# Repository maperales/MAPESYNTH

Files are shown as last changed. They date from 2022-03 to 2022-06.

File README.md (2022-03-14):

# MAPESYNTH
Documentación y ficheros de diseño y programación del sistema Mapesynth
-
En este repositorio se encuentra toda la información necesaria para poder replicar el sistema MAPESYNTH completo.

El sistema MAPESYNTH (Midi Advanced Programmable Educational Synthesizer) es un dispositivo que, convenientemente programado, puede hacer de instrumento MIDI, controlador MIDI, secuenciador MIDI y sintetizador MIDI, o cualquier combinación de las anteriores. Al ser de código abierto, puede ser reprogramado para cumplir otras funciones.



El hardware tiene la estructura de un Boosterpack tipo XL (40 pines), que se puede acomodar sobre multitud de Launchpads de Texas Instruments. En concreto, los ejemplos software y el diseño están enfocados al uso del microcontrolador MSP430FR5994, por lo que será necesario disponer del Launchpad MSP-EXP430FR5994 para su manejo. Los ficheros de diseño se encuentran en Eagle, aunque la etapa final se ha realizado en EasyEDA. Se ofrece igualmente el fichero de EasyEDA, por si sólo se desea fabricar tal cual, sin ningún cambio.

El software se ha desarrollado en Code Composer Studio, disponible de manera gratuita en la página de Texas Instruments. Probablemente se pueda reutilizar con algunos cambios menores con otros compiladores de la familia MSP430, aunque no se ha probado.

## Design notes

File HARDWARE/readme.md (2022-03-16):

Ficheros de Hardware
==
En esta carpeta están los ficheros necesarios para replicar el hardware del sistema MAPESYNTH. En la carpeta EAGLE se encuentran los ficheros de Eagle, por si se quiere hacer alguna variación de los mismos. Están diseñados con la versión Eagle Standard (free) 7.7.0, accesible aún (espero) en la página web de Autodesk:

http://eagle.autodesk.com/eagle/software-versions/1

Se incluye el fichero de esquema, el rutado, y un fichero de librería con los elementos usados. 


Aparte de los ficheros fuente, se ofrecen también, en la carpeta EasyEDA, el fichero (comprimido) con el GERBER de la placa para ser fabricada, y el archivo de EasyEDA que se ha creado para ello. Este archivo también es editable, pero no tiene "soporte de esquema", está importado directamente como PCB desde Eagle y modificado para añadirle la última capa de serigrafía y el acabado final. 


Respecto a la lista de componentes, se indican los enlaces de los diferentes elementos que se han comprado para el desarrollo de la placa. Muchos de ellos son críticos en cuanto a la forma y tamaño de la huella (potenciómetros, joystick, pantalla...) y otros son estándar (resistencias y condensadores SMD o thru hole)

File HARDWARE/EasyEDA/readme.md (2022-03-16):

Ficheros EasyEDA
--
En esta carpeta se encuentra el fichero para poder modificar la versión final del diseño (mapesynth.json), en EasyEDA. Este software se puede ejecutar en modo online en su propia página web
o bien descargarlo para ejecutarlo como aplicación de escritorio. La principal ventaja es asegurar la compatibilidad con la empresa JLCPCB, fabricante de prototipos de PCB
con coste bastante contenido. 

Igualmente, si no se quiere hacer ningún cambio en absoluto, se puede usar el fichero comprimido que tiene los archivos GERBER necesarios para la fabricación (mapesynth.zip), y tal cual se puede 
mandar a fabricar.

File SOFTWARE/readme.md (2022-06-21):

Software de manejo del sistema MAPESYNTH
--

En esta carpeta se incluye todo el sw necesario para hacer funcionar el sistema, así como varios ejemplos de manejo del mismo. Cada ejemplo se incluye en un fichero .c 

Los siguentes ficheros son necesarios para el funcionamiento de los ejemplos:

- **mapesynth.c / mapesynth.h**: librería de funciones de manejo del sistema. Incluye las funciones de bajo nivel (HAL) y las funciones de manejo en alto nivel, así como algunas funciones de manejo de la pantalla.
- **formas.h / formas.c**: formas de onda digitalizadas, y definiciones de constantes para calcular las fases al muestrear las formas con las frecuencias de las notas de la escala occidental temperada (LA=440Hz). Solo será necesario si se va a usar el sistema como sintetizador
- **nokia5110.c / nokia5110.h**: librería de funciones de manejo de la pantalla. Basada en la existente en la página 43oh.com

Los ejemplos disponibles son los siguientes:

- **MIDI_CTRL1.c**: El sistema funciona como un secuenciador, reproduciendo canciones almacenadas. Se puede elegir la canción, cambiar la velocidad y seleccionar el canal MIDI al que se mande la secuencia.
- **MIDI_CTRL2.c**:El sistema funciona como un controlador MIDI interpuesto entre un teclado y un sintetizador. Cuando recibe una nota, la retransmite, pudiendo modificar la nota, el valor de la velocidad y el pitch. También podrá incluir mensajes de Pedal Sustain On/Off.
- **MIDI_SYNTH1.c**: Funciona como sintetizador aditivo básico, sumando cualquiera de las formas almacenadas, pudiendo variar en el momento de la suma su amplitud y fase
- **MIDI_SYNTH2.C**: versión del anterior, incorporando la modulación ADSR. Se pueden variar los parámetros de tiempos de ataque, decay, release y valor de Sustain.  
- **MIDI_SYNTH3.C**: Versión del anterior, incorporando la posibilidad de grabar formas de onda ya mezcladas y recuperarlas más adelante. Hace uso de la memoria FRAM del dispositivo, y cambia ligeramente el uso de los vectores de forma de onda.

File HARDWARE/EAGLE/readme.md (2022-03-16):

Ficheros EAGLE
--
En principio, bastará con copiar los ficheros .brd y .sch en el mismo directorio para poder abrirlos. El fichero de librería (.lbr) se ofrece como compilación de los elementos, pero probablemente no sea necesario.

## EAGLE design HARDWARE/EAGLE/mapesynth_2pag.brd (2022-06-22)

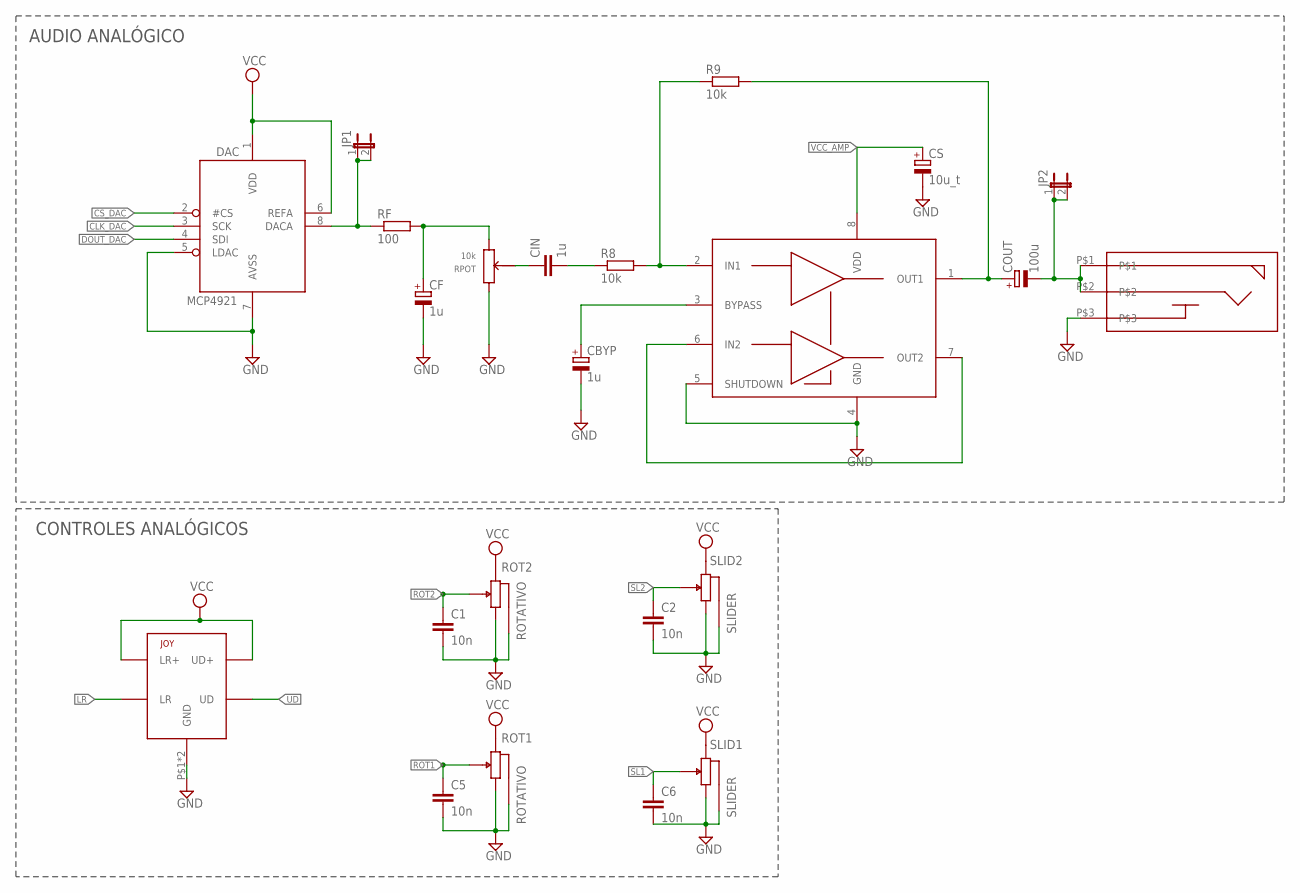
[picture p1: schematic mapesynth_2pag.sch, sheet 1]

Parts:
AMP: TPA6111; SO-08
C1, C2, C5, C6: 10n; C050-024X044
CBYP: 1u; 153CLV-0405
CF: 1u; 153CLV-0405
CIN: 1u; C1206
COUT: 100u; 153CLV-0605
CS: 10u_t; CT3528
DAC: MCP4921EN_SMD; SO-08
JOY: JOYSTICK; PLACAJSTICK
JP1, JP2: JP1E; JP1
R8, R9: 10k; M1206
RF: 100; M1206
ROT1, ROT2: ROTATIVO
RPOT: 10k; POT_VOL
SLID1, SLID2: SLIDER
U$4: JACK_3_5MM_VA; JACK3_5MM_V2

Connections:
CLK_DAC: DAC.3 (SCK); also elsewhere on the board
CS_DAC: DAC.2 (#CS); also elsewhere on the board
DOUT_DAC: DAC.4 (SDI); also elsewhere on the board
GND: AMP.4 (GND), AMP.5 (SHUTDOWN), C1.2, C2.2, C5.2, C6.2, CBYP.-, CF.-, CS.-, DAC.5 (LDAC), DAC.7 (AVSS), JOY.P$1 (GND), JOY.P$8 (GND), ROT1.A (1), ROT1.GND1 (GND), ROT1.GND2 (GND), ROT2.A (1), ROT2.GND1 (GND), ROT2.GND2 (GND), RPOT.P$1, SLID1.1, SLID1.4 (GND), SLID1.5 (GND), SLID1.6 (GND), SLID1.7 (GND), SLID2.1, SLID2.4 (GND), SLID2.5 (GND), SLID2.6 (GND), SLID2.7 (GND), U$4.P$3; also elsewhere on the board
LR: JOY.P$3 (LR), JOY.P$6 (LR); also elsewhere on the board
unnamed: DAC.8 (DACA), JP1.1, JP1.2, RF.1
unnamed: CF.+, RF.2, RPOT.P$3
unnamed: CIN.1, RPOT.P$2
unnamed: CIN.2, R8.1
unnamed: AMP.2 (IN1), R8.2, R9.1
unnamed: AMP.1 (OUT1), COUT.+, R9.2
unnamed: COUT.-, JP2.1, JP2.2, U$4.P$1, U$4.P$2
unnamed: AMP.6 (IN2), AMP.7 (OUT2)
unnamed: AMP.3 (BYPASS), CBYP.+
ROT1: C5.1, ROT1.C (2); also elsewhere on the board
ROT2: C1.1, ROT2.C (2); also elsewhere on the board
SL1: C6.1, SLID1.2; also elsewhere on the board
SL2: C2.1, SLID2.2; also elsewhere on the board
UD: JOY.P$2 (UD), JOY.P$7 (UD); also elsewhere on the board
VCC: DAC.1 (VDD), DAC.6 (REFA), JOY.P$4 (LR+), JOY.P$5 (UD+), ROT1.B (3), ROT2.B (3), SLID1.3, SLID2.3; also elsewhere on the board
VCC_AMP: AMP.8 (VDD), CS.+; also elsewhere on the board

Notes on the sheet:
AUDIO ANALÓGICO
CONTROLES ANALÓGICOS

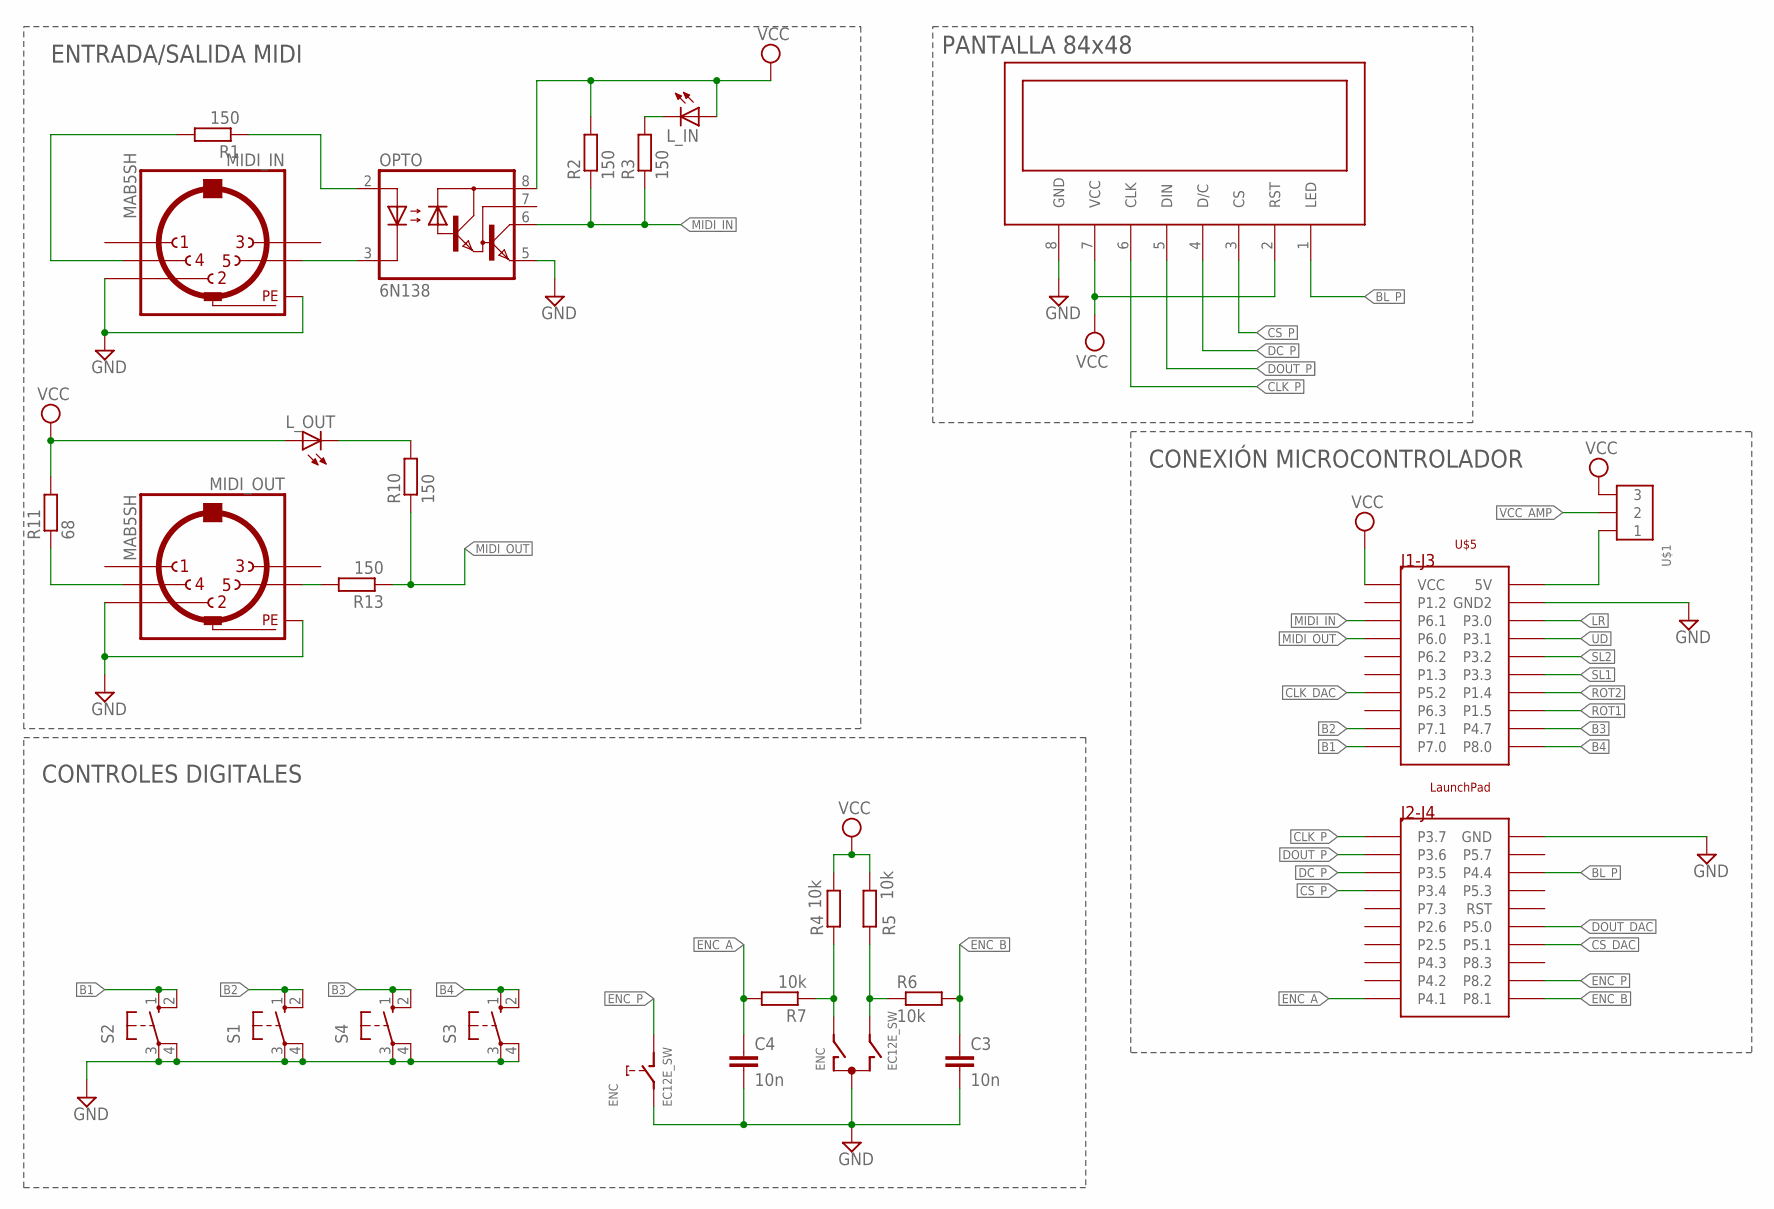
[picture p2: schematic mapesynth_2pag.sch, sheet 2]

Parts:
C3, C4: 10n; C050-024X044
ENC: EC12E_SW; ALPS_EC12E_SW
L_IN: LED5MM
L_OUT: LED5MM
MIDI_IN: MAB5SH
MIDI_OUT: MAB5SH
OPTO: 6N138; DIL08
R1, R2, R3, R10, R13: 150; 0207/10
R4, R5, R6, R7: 10k; R1206
R11: 68; 0207/10
S1, S2, S3, S4: 40-XX; B3F-40XX
U$1: JP3
U$3: NOKIA_5110
U$5: LAUNCHPAD_XL

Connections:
B1: S2.1 (S), S2.2 (S1), U$5.P$10 (P7.0)
B2: S1.1 (S), S1.2 (S1), U$5.P$9 (P7.1)
B3: S4.1 (S), S4.2 (S1), U$5.P$29 (P4.7)
B4: S3.1 (S), S3.2 (S1), U$5.P$30 (P8.0)
BL_P: U$3.1 (LED), U$5.P$18 (P4.4)
CLK_DAC: U$5.P$7 (P5.2); also elsewhere on the board
CLK_P: U$3.6 (CLK), U$5.P$40 (P3.7)
CS_DAC: U$5.P$14 (P5.1); also elsewhere on the board
CS_P: U$3.3 (CS), U$5.P$37 (P3.4)
DC_P: U$3.4 (D/C), U$5.P$38 (P3.5)
DOUT_DAC: U$5.P$15 (P5.0); also elsewhere on the board
DOUT_P: U$3.5 (DIN), U$5.P$39 (P3.6)
ENC_A: C4.1, R7.2, U$5.P$31 (P4.1)
ENC_B: C3.1, R6.2, U$5.P$11 (P8.1)
ENC_P: ENC.D (1), U$5.P$12 (P8.2)
GND: C3.2, C4.2, ENC.C, ENC.E (2), MIDI_IN.2, MIDI_IN.PE, MIDI_IN.PE@ (PE), MIDI_OUT.2, MIDI_OUT.PE, MIDI_OUT.PE@ (PE), OPTO.5 (GND), S1.3, S1.4 (P1), S2.3, S2.4 (P1), S3.3, S3.4 (P1), S4.3, S4.4 (P1), U$3.8 (GND), U$5.P$20 (GND), U$5.P$22 (GND2); also elsewhere on the board
LR: U$5.P$23 (P3.0); also elsewhere on the board
MIDI_IN: OPTO.6 (VO), R2.1, R3.1, U$5.P$3 (P6.1)
MIDI_OUT: R10.1, R13.1, U$5.P$4 (P6.0)
unnamed: MIDI_IN.4, R1.2
unnamed: MIDI_IN.5, OPTO.3 (C)
unnamed: OPTO.2 (A), R1.1
unnamed: U$1.P$1 (1), U$5.P$21 (5V)
unnamed: MIDI_OUT.4, R11.1
unnamed: L_IN.K (C), R3.2
unnamed: L_OUT.K (C), R10.2
unnamed: MIDI_OUT.5, R13.2
unnamed: ENC.A, R4.1, R7.1
unnamed: ENC.B, R5.1, R6.1
ROT1: U$5.P$28 (P1.5); also elsewhere on the board
ROT2: U$5.P$27 (P1.4); also elsewhere on the board
SL1: U$5.P$26 (P3.3); also elsewhere on the board
SL2: U$5.P$25 (P3.2); also elsewhere on the board
UD: U$5.P$24 (P3.1); also elsewhere on the board
VCC: L_IN.A, L_OUT.A, OPTO.8 (VCC), R2.2, R4.2, R5.2, R11.2, U$1.P$3 (3), U$3.2 (RST), U$3.7 (VCC), U$5.P$1 (VCC); also elsewhere on the board
VCC_AMP: U$1.P$2 (2); also elsewhere on the board

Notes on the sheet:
ENTRADA/SALIDA MIDI
PANTALLA 84x48
CONTROLES DIGITALES
CONEXIÓN MICROCONTROLADOR

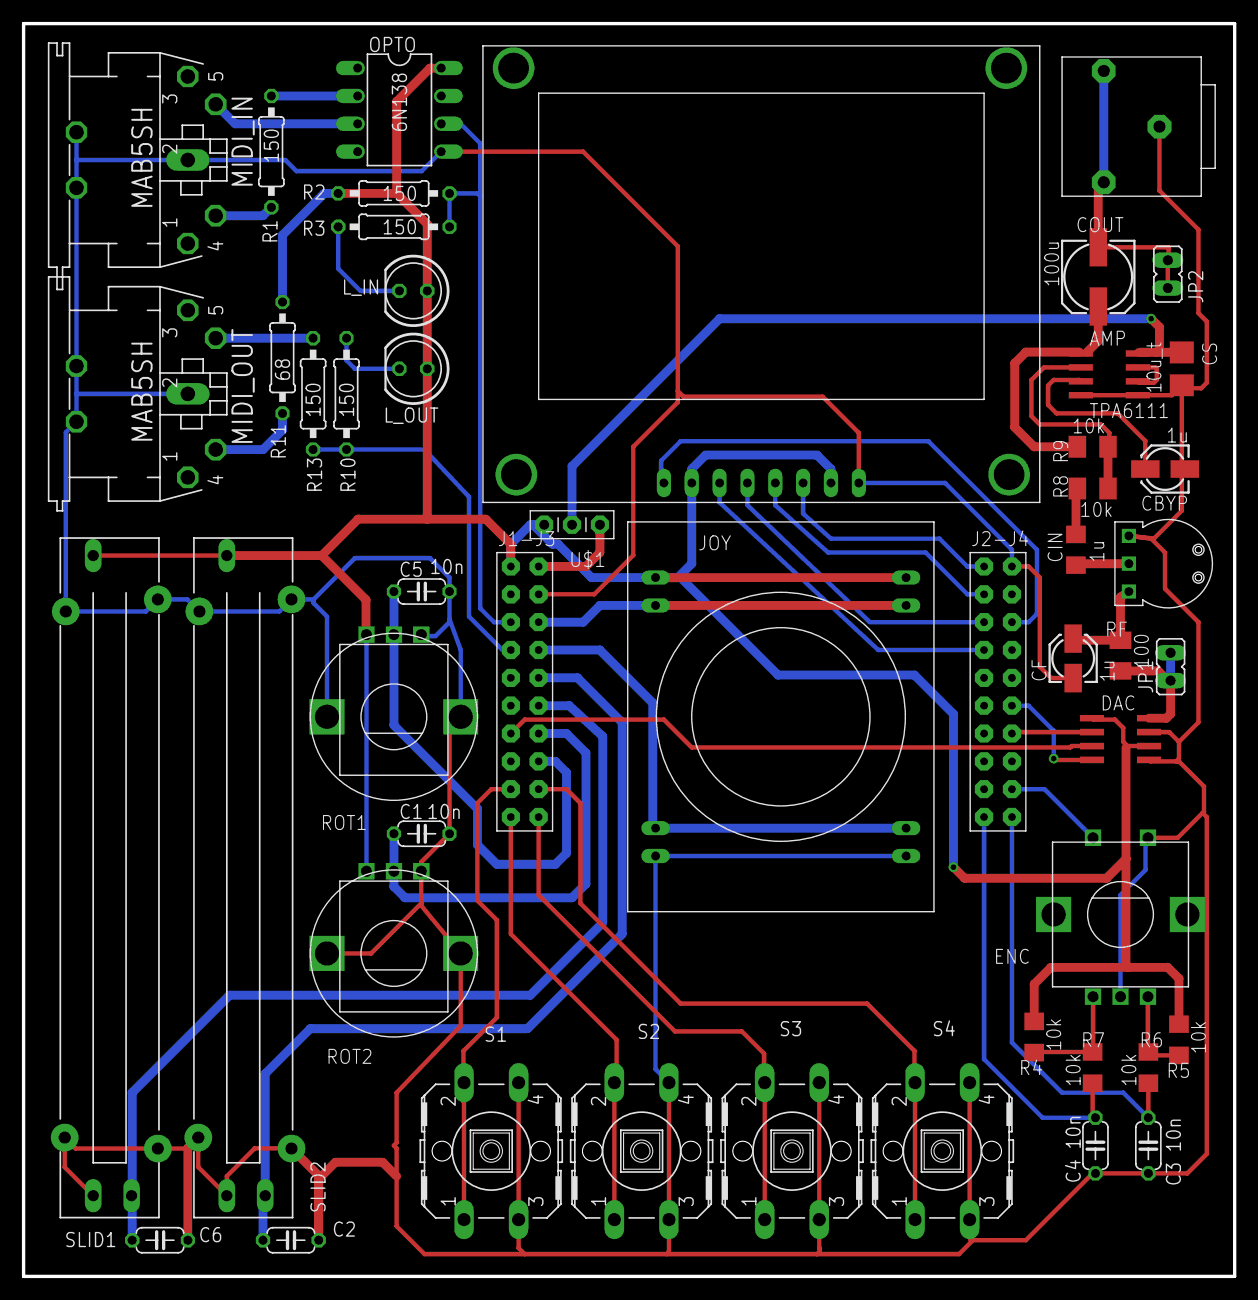
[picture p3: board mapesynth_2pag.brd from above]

Board: 2 copper layers, 110.5 x 114.3 mm, 48 parts (0 on the bottom side), 45 nets.

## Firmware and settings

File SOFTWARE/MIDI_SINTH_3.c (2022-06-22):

/************************************************************
 * Segundo ejemplo de MAPE-Synth como sintetizador
 * MODO 1: forma de onda
 *      B1: p.inst-
 *      B2: p.inst+
 *      B3: quita inst
 *      B4: añade inst
 *      SL1: Amplitud inst (0..100)
 *      SL2: Fase inst (0..360)
 * MODO 2: ADSR
 *      B1: param-
 *      B2: param+
 *      B3: reset param
 *      B4: guarda param
 *      JOY_Y: sube o baja el param. 1 o 10
 * MODO 3: Guarda Forma Onda
 *      B1: puntero -
 *      B2  Puntero +
 *      B3: Guardar
 *      B4: Guardar
 *
 ************************************************************/

#include <msp430.h>
#include <stdio.h>
#include "formas.h"
#include "mapesynth.h"
#include "nokia5110.h"

unsigned int medida, num;
//unsigned char MSD=0, LSD=0;
unsigned char i=0, Espera=0;
char cadena[20];
volatile unsigned char nota=0, inst=0;
unsigned int fase=0;
unsigned int frec=0;


char Nom[]="01234567ABCD";

void normaliza(int *vector)
{
    int i, max=0;
    float factor=0.0;
    for(i=0;i<128;i++){
        if(abs(vector[i])>max) max=abs(vector[i]);
    }
    factor= 510.0/(float)max;
    for(i=0;i<128;i++) vector[i]=(int)(factor*(float)vector[i]);
}



char Mezcla[NUMINST+4]={0};
unsigned char Ampl[NUMINST+4]={0};
unsigned char Fase[NUMINST+4]={0};
int forma[128];


int t_nota, t_nota_off, tA, tD, tR, SUST, Amp_int;
float Amp, Amp_i, Amp_d, Amp_r;

char nota_act=0;
enum modos {FORMA, ADSR, SAVE, MIDI_SNIFF};

char modo=FORMA;
int param_adsr[4]={10,10,90,10};
int param_adsr_default[4]={10,10,90,10};
signed char valor_param, par_act=0;
char nombre_param[]="ADSR";

char Vib_on=0, Trem_on=0;
int Vel_vib=0, Amp_trem=0;
int NMAX=0;

void calcula_onda(void)
{
    char i,j;
    for(i=0;i<128;i++)
    {
        forma[i]=0;
        for(j=0;j<NMAX;j++)
        {
            if(Mezcla[j]) forma[i]+=((Ampl[j]>>1)*Instrum[j][(128+i+Fase[j])&0x7F])>>6;
        }
    }
    normaliza(forma);
    dibuja_onda(forma);
}

void LFO(void)  //LFO: Aplicación del ADSR y efectos
{
    if(nota==1)
    {
        t_nota++;
        if(t_nota<=param_adsr[0])   //A
        {
            Amp+=Amp_i;
            if(Amp>1000) Amp=1000;
        }else
        {
            if(t_nota<(param_adsr[0]+param_adsr[1]))  //D
            {
                Amp-=Amp_d;
                if(Amp<param_adsr[2]) Amp=param_adsr[2];
            }else
            {
                t_nota=param_adsr[0]+param_adsr[1];  //S

            }
        }
    }
    if(nota==2)
    {
        t_nota_off++;
        if(t_nota_off<param_adsr[3]) //R
        {
            Amp-=Amp_r;
            if(Amp<0)Amp=0;
        }
        else
        {
            nota=0;
        }
    }
    Amp_int=(int)(Amp/20.0);
}

int calcula_dac(void)
{
    int dac_calc= 2046;

    if(nota)
    {
        dac_calc = (forma[(fase>>8)&0x7f]);
        fase += frec;
        dac_calc=(dac_calc*(Amp_int))/25;
        dac_calc+=2046;
    }
    return dac_calc;
}

void VCO(void)
{
    int dac;
    dac=calcula_dac();
    saca_dac(dac);
}




void cambia_param(char param)
{
    switch(param)
    {
    case 0:
        Amp_i=1000.0/(float)param_adsr[0];
        break;
    case 1:
        Amp_d=(float)(10*(100-param_adsr[2]))/param_adsr[1];
        break;
    case 2:
        Amp_d=(float)(10*(100-param_adsr[2]))/param_adsr[1];
        Amp_r=(float)(10*param_adsr[2])/(float)param_adsr[3];
        break;
    case 3:
        Amp_r=(float)(10*param_adsr[2])/(float)param_adsr[3];
        break;
    }
}



void calcula_modo(void)
{
    char nuevo_modo;
    if(Enc_val>5) Enc_val=-2;
    if(Enc_val<-2) Enc_val=5;

    if(Enc_val>-1 && Enc_val<3) nuevo_modo=0;
    if(Enc_val>-3 && Enc_val<0) nuevo_modo=2;
    if(Enc_val<6 && Enc_val>2) nuevo_modo=1;
    if(nuevo_modo !=modo)
    {
        clearLCD();
        modo=nuevo_modo;
        if(modo==FORMA) dibuja_onda(forma);
    }

}

int Save=0, Guardando=0;

int main(void)
{
    char i,j,Comm;
    HAL_conf_MC();
    initLCD();
    clearLCD();
    writeBlockToLCD(Logotipo, 504);
    HAL_habilita_ints();
    espera_boton();
    NMAX=copia_ondas();
    clearLCD();
    HAL_conf_VCO();         //Interrupción a 20kHz
    HAL_conf_LFO();         //Interrupción a 100Hz

     Amp_i=1000.0/(float)param_adsr_default[0];
     Amp_d=(float)(10*(100-param_adsr_default[2]))/param_adsr_default[1];
     Amp_r=(float)(10*param_adsr_default[2])/(float)param_adsr_default[3];

    while(1)
    {
        if(Msg)
        {
            Msg=0;
            manda_midi(Buff);
            Comm=Buff[0]&0xF0;
            if(Comm==0x80 || (Comm==0x90 && Buff[2]==0))
            {
                if(Buff[1]==nota_act)
                {
                    nota=2;
                    t_nota_off=0;
                }
            }
            else if(Comm==0x90)
            {
                nota_act=Buff[1];
                frec=Freq[nota_act-OFFSET_NOTA];
                fase=0;
                nota=1;
                t_nota=0;
                Amp=0.0;
                Amp_int=0;
            }
            else if(Comm==PITCH)
            {
                if(Buff[2]>64) //Pitch up
                {
                    frec=Freq[nota_act-OFFSET_NOTA]+((Freq[nota_act+2-OFFSET_NOTA]-Freq[nota_act-OFFSET_NOTA])*(Buff[2]-64))/64;
                }
                else    //Pitch Down
                {
                    frec=Freq[nota_act-OFFSET_NOTA]+((Freq[nota_act-OFFSET_NOTA]-Freq[nota_act-2-OFFSET_NOTA])*(Buff[2]-64))/64;
                }
            }
        }
        calcula_modo();

        if(modo==FORMA)     //Modo selección de forma de onda
        {
            if(GATE[1] && TRIG[1])
            {
                TRIG[1]=0;
                inst++;
                if(inst>=NMAX)inst=0;
            }
            if(GATE[0] && TRIG[0])
            {
                TRIG[0]=0;
                if(inst!=0){
                    inst--;
                }
                else
                {
                    inst=NMAX-1;
                }

            }
            if(GATE[3] && TRIG[3])
            {
                TRIG[3]=0;
                Mezcla[inst]=1;
                Ampl[inst]=SL1;
                Fase[inst]=SL2;
                calcula_onda();
            }
            if(GATE[2] && TRIG[2])
            {
                TRIG[2]=0;
                Mezcla[inst]=0;
                calcula_onda();
            }

            sprintf(cadena,"I:%c A:%d F:%d   ",Nom[inst],(SL1*100)>>7,(SL2*360)>>7);
            escribe(0,4,cadena);
            sprintf(cadena, "Mix:         ");
            j=0;
            for(i=0;i<NMAX;i++)
            {
                if(Mezcla[i]){
                    cadena[4+j]=Nom[i];
                    j++;
                }
            }
            escribe(0,5,cadena);
        }
        if(modo==ADSR)      //Modo envolvente
        {
            if(GATE[0] && TRIG[0])  //decrementa selección de parámetro
            {
                TRIG[0]=0;
                if(par_act>0){
                    par_act--;
                }else par_act=3;
                valor_param=param_adsr[par_act];
            }
            if(GATE[1] && TRIG[1]) //incrementa selección de parámetro
            {
                TRIG[1]=0;
                if(par_act<3){
                    par_act++;
                }else par_act=0;
                valor_param=param_adsr[par_act];
            }
            if(GATE[2] && TRIG[2]) //Da valor por defecto al parámetro seleccionado
            {
                TRIG[2]=0;
                param_adsr[par_act]=param_adsr_default[par_act];
                cambia_param(par_act);
            }
            if(GATE[3] && TRIG[3]) //Asigna nuevo valor al parámetro seleccionado
            {
                TRIG[3]=0;
                param_adsr[par_act]=valor_param;
                cambia_param(par_act);
            }
            if(JOY_Y>80)    //Incrementa parámetro
            {
                valor_param++;
                if(JOY_Y>110) valor_param+=3;
                if(valor_param>100) valor_param=100;
            }
            if(JOY_Y<48)    //Decrementa parámetro
            {
                valor_param--;
                if(JOY_Y<14) valor_param-=3;
                if(valor_param<1) valor_param=1;
            }
            sprintf(cadena,"A:%d0ms     ",param_adsr[0]);
            escribe(0, 0, cadena);
            sprintf(cadena,"D:%d0ms     ",param_adsr[1]);
            escribe(0, 1, cadena);
            sprintf(cadena,"S:%d%%     ",param_adsr[2]);
            escribe(0, 2, cadena);
            sprintf(cadena,"R:%d0ms     ",param_adsr[3]);
            escribe(0, 3, cadena);
            if(par_act==2)            
            {
                sprintf(cadena,"S:%d%%     ",valor_param);
            }
            else
            {
                sprintf(cadena,"%c:%d0ms     ",nombre_param[par_act],valor_param);
            }
            escribe(0, 5, cadena);
        }
        if(modo==SAVE)        //Por desarrollar
        {
            escribe(0, 1, "Modo SAVE");
            if(GATE[1] && TRIG[1])
            {
                TRIG[1]=0;
                Save++;
                if(Save==4) Save=0;
            }
            if(GATE[0] && TRIG[0])
            {
                TRIG[0]=0;

                if(Save==0)
                {
                    Save=3;
                }
                else
                {
                    Save--;
                }
            }
            if(GATE[2] && TRIG[2])
            {
                TRIG[2]=0;
                if(Save_Wave[Save*128]!=0xffff)
                {
                    escribe(0,2,"Sobreescribir?");
                    escribe(0,3,"S4: SI");
                    Guardando=1;
                }
                else
                {
                    for(i=0;i<128;i++) Save_Wave[Save*128+i]=forma[i];
                    sprintf(cadena, "Guardado en S%d", Save);
                    escribe(0,3,cadena);
                    NMAX=copia_ondas();

                }
            }
            if(GATE[3] && TRIG[3])
            {
                TRIG[3]=0;
                if(Guardando){
                for(i=0;i<128;i++) Save_Wave[Save*128+i]=forma[i];
                sprintf(cadena, "Guardado en S%d", Save);
                escribe(0,3,cadena);
                Guardando=0;
                NMAX=copia_ondas();
                }
            }
            sprintf(cadena,"Sel: %d ",Save);
            escribe(0,5,cadena);

        }





    }
}

//unsigned int ciclos=0;

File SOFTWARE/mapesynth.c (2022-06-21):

#include <mapesynth.h>
#include <msp430.h>
#include "nokia5110.h"
#include "formas.h"

int n, N_MAX, N_M[8]={3,3,3,3,2,2,3,3};
char Buff[12];
char Msg=0;

int Slider1, Slider2, Pot1, Pot2;
char Cambio_SL1,Cambio_SL2,Cambio_POT1,Cambio_POT2,Cambio_x,Cambio_y;
unsigned int JOY_X=0, JOY_Y=0, SL1=0, SL2=0, ROT1=0, ROT2=0;
int t=0;
volatile char GATE[]={0,0,0,0};
volatile char TRIG[]={0,0,0,0};

volatile int Enc_val=0;
int *Save_Wave= (int *)0x6000;
int *Instrum[12];
int copia_ondas(void)
{
   char i,j;
   for (i=0;i<NUMINST;i++)
   {
       Instrum[i]=SAMPLES[i];
   }
   for (i=0;i<4;i++)
      {
       if(Save_Wave[i*128]!=0xffff)
       {
           Instrum[NUMINST+i]= (int*)(Save_Wave + i*128);
       }
       else
       {
           break;
       }
      }
   return(NUMINST+i);
}

void manda_midi( char *msg)
{
	int i;
	for(i=0;i<3;i++)
	{
	    manda_char(msg[i]);
	}
}


void manda_char( char a)
{
		 while (!(UCA3IFG & UCTXIFG)); // Poll TXIFG to until set
		    UCA3TXBUF = a;       // TX -> RXed character
}

void HAL_clk_16(void)
{
    // Configure one FRAM waitstate as required by the device datasheet for MCLK
      // operation beyond 8MHz _before_ configuring the clock system.
      FRCTL0 = FRCTLPW | NWAITS_1;

      // Clock System Setup
      CSCTL0_H = CSKEY_H;                     // Unlock CS registers
      CSCTL1 = DCOFSEL_0;                     // Set DCO to 1MHz
      // Set SMCLK = MCLK = DCO, ACLK = VLOCLK
      CSCTL2 = SELA__VLOCLK | SELS__DCOCLK | SELM__DCOCLK;
      // Per Device Errata set divider to 4 before changing frequency to
      // prevent out of spec operation from overshoot transient
      CSCTL3 = DIVA__4 | DIVS__4 | DIVM__4;   // Set all corresponding clk sources to divide by 4 for errata
      CSCTL1 = DCOFSEL_4 | DCORSEL;           // Set DCO to 16MHz
      // Delay by ~10us to let DCO settle. 60 cycles = 20 cycles buffer + (10us / (1/4MHz))
      __delay_cycles(60);
      CSCTL3 = DIVA__1 | DIVS__1 | DIVM__1;   // Set all dividers to 1 for 16MHz operation
      CSCTL0_H = 0;                           // Lock CS registers                      // Lock CS registers

}



void HAL_conf_MC(void){

	/*Parar el WatchDog*/

	WDTCTL = WDTPW | WDTHOLD;

    //Configurar pines E/S botones y Encoder

    P7REN |= BIT0+BIT1; //B1, B2
    P7OUT |= BIT0+BIT1;
    P8REN |=BIT0+BIT2;  //B4, ENC_P
    P8OUT |=BIT0+BIT2;
    P4REN |=BIT7;       //B3
    P4OUT |=BIT7;

    P1DIR |= BIT0; //P1.0 para señalizar
    /****************************
     * INterrupción del encoder en P4.1
     *
     *****************************/
    P4IFG =0;
    P4IES = BIT1;  // Flanco bajada
    P4IE  = BIT1;   // habilitar int. P4.1



    //Configurar entradas analógicas:

    P3SEL1 |= BIT0+BIT1+BIT2+BIT3;    //JoyX, JoyY, SL1, SL2
    P3SEL0 |= BIT0+BIT1+BIT2+BIT3;
    P1SEL0 |= BIT5+BIT4;    //Rot1, Rot2
    P1SEL0 |= BIT5+BIT4;


    P6SEL1 &= ~(BIT0 | BIT1);
    P6SEL0 |= (BIT0 | BIT1);                // USCI_A3 UART operation

    PJSEL0 |= BIT4 | BIT5;

    P5REN |= BIT5+BIT6;
    P5OUT |= BIT5+BIT6;

    /**********
     * USCIB1 como SPI:
     * P5.0 SIMO: SEL1=0, SEL0=1
     * P5.2 CLK:  SEL1=0, SEL0=1
     * P5.1 CS (I/O)
     ***********/

    P5SEL1 &= ~(BIT0+BIT2);
    P5SEL0 |= BIT0+BIT2;
    P5OUT |= BIT1;
    P5DIR |= BIT1;

    /********************************************
     * Configurar pantalla:
     *******************************/

    P3OUT |= LCD5110_SCE_PIN + LCD5110_DC_PIN;
    P3OUT &= ~LCD5110_SCLK_PIN;
    P3DIR |= LCD5110_SCE_PIN + LCD5110_DC_PIN+LCD5110_SCLK_PIN + LCD5110_DN_PIN;
    BL_ON;  //Backlight on
    P4DIR |= BIT4;

    // Disable the GPIO power-on default high-impedance mode to activate
    // previously configured port settings
    PM5CTL0 &= ~LOCKLPM5;

    ADC12CTL0 = ADC12SHT0_2 | ADC12ON |ADC12MSC;      // Sampling time, S&H=16, ADC12 on

      ADC12CTL1 = ADC12SHP |ADC12CONSEQ_1 |ADC12SSEL_3 |ADC12DIV_0 ;                   // Use sampling timer
      ADC12CTL2 |= ADC12RES_2;                // 12-bit conversion results
      ADC12CTL3 |= ADC12CSTARTADD_0;
      ADC12MCTL0 |= ADC12INCH_12;
      ADC12MCTL1 |= ADC12INCH_13;
      ADC12MCTL2 |= ADC12INCH_14;
      ADC12MCTL3 |= ADC12INCH_15;
      ADC12MCTL4 |= ADC12INCH_4;
      ADC12MCTL5 |= ADC12INCH_5 | ADC12EOS;

      ADC12IER0 |= ADC12IE5  ;                  // Enable ADC conv complete interrupt
      HAL_clk_16();

    // ACLK, contmode, clear TAR, enable overflow interrupt
    TA0CTL = TASSEL__SMCLK | MC__UP | ID__8| TACLR  ; //2MHz
//    TA0CTL = TASSEL__ACLK | MC__UP | TACLR  ;

    TA0CCTL0 = CCIE;
    TA0CCR0 = 39999;  //2M/40000 /50Hz

   // TA0CCR0 = 3200;  //32kHz /3200: 10Hz

    /***************************
     * CONFIG. UCA3 para MIDI
     * 31250bps
     **********/
     UCA3CTLW0 = UCSWRST;                    // Put eUSCI in reset
     UCA3CTLW0 |= UCSSEL__SMCLK;             // CLK = SMCLK (16MHz)
     // Baud Rate calculation
     // 16000000/(16*31250) = 32
     // Fractional portion = 0
     // User's Guide Table 21-4: UCBRSx = 0x04
     // UCBRFx = int ( (52.083-52)*16) = 1 0.021*13=0.33 (0)

     UCA3BRW = 32;
     UCA3MCTLW |= UCOS16;   // OVERSAMPLING con modulation=0
     UCA3CTLW0 &= ~UCSWRST;                  // Initialize eUSCI
     UCA3IE |= UCRXIE;                       // Enable USCI_A3 RX interrupt


     /*****************
      * CONF. UCB1 como SPI:
      *
      */
        UCB1CTLW0 = UCSWRST;                    // **Put state machine in reset**
        UCB1CTLW0 |= UCMST | UCSYNC | UCCKPL | UCMSB; // 3-pin, 8-bit SPI master
                                                // Clock polarity high, MSB
        UCB1CTLW0 |= UCSSEL__SMCLK;              // ACLK
        UCB1BRW = 0x00;                         // /2
        //UCB1MCTLW = 0;                          // No modulation
        UCB1CTLW0 &= ~UCSWRST;                  // **Initialize USCI state machine**
}

char Msg_Rx[3];
#pragma vector=EUSCI_A3_VECTOR
__interrupt void INterrupcion_RX_A3(void)
{

    char Buf_RX;
    Buf_RX=UCA3RXBUF;
    if(Buf_RX>=0x80)
    {
        n=0;
        N_MAX=N_M[((Buf_RX>>4)&0x07)];
    }
    Msg_Rx[n]=Buf_RX;
    n++;
    if(n==N_MAX){
        Msg=1;
        Buff[0]=Msg_Rx[0];
        Buff[1]=Msg_Rx[1];
        Buff[2]=Msg_Rx[2];
    }
}

void lee_botones(void)
{
    char i, bot[4];
    bot[0]=B1;
    bot[1]=B2;
    bot[2]=B3;
    bot[3]=B4;

    for(i=0;i<4;i++)
    {
        if(bot[i] !=GATE[i])
        {
                TRIG[i]=1;
        }
        GATE[i]=bot[i];
    }
}
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

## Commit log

2022-03-16 Add files via upload
    Fichero EasyEDA editable, con los retoques "cosméticos" en la capa de serigrafía.
2022-03-16 Fichero GERBER para fabricación
